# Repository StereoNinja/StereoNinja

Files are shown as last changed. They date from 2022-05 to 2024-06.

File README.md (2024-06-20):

# Stereo Ninja

Stereo Ninja is a DIY digital stereo microscope

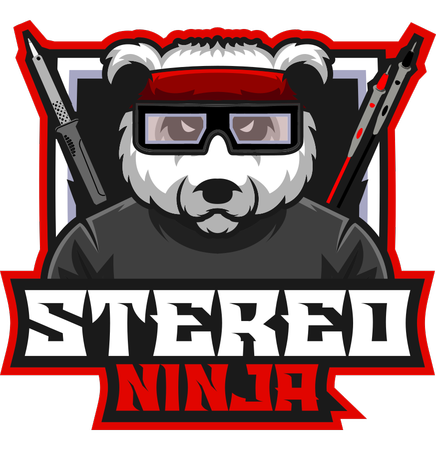
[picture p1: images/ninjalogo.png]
Stereo Ninja Logo


# Overview

If you ever soldered SMT components or looked for issues on one of those tiny PCBs, you know that using a good microscope helps a lot, especially if it is a stereo microscope. But a good stereo microscope comes with a hefty price tag, so it's not for everyone. A cheap alternative is using a "usb microscope", but then of course you do not have stereo vision.

Our idea is to combine best of both worlds. Having proper stereoscopic view on your work piece and using relatively cheap digital components for archiving that. If you already have a 3D capable monitor, you only need a pair of cameras with suitable optics and some electronics for combining the two video streams into a single one that your monitor understands. We are using a Raspberry Pi for that (what else? ;-)).

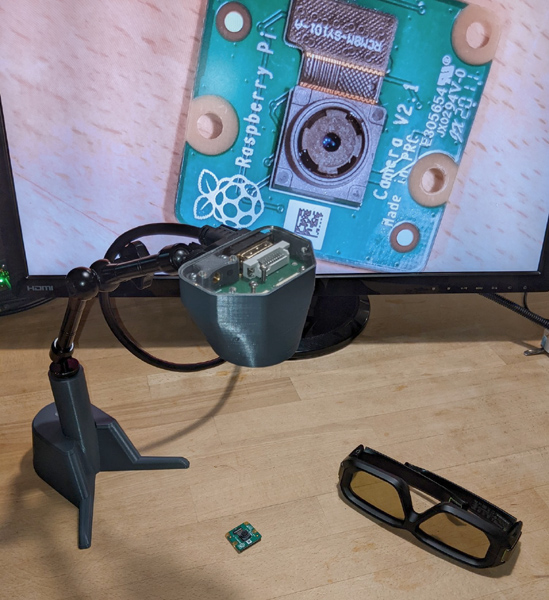
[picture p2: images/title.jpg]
Stereo Ninja


# Details

Stereo Ninja is a dual camera setup for stereoscopic microscopy. The heart of the project is a Raspberry Pi. To be precise, you need a Raspberry Pi 3 or 4 Compute Module and a breakout board that gives you access to both MIPI CSI camera input ports the chip set offers, but is not available at the standard Raspberry Pi 3 or 4 versions. Then of course, you need 2 RaspberryPi-compatible cameras with suitable lenses. Our microscope setup is meant for electronics work, so we chose lenses that do not give you that much of a magnification, but permits an adequate lens-object distance for conveniently working under it. Then of course, you need a 3D monitor for displaying the stereoscopic view on your workpiece. We chose a fast 3D-capable gaming monitor with shutter goggles. Finally, a nice stand for you camera is needed.

All these components allow a selection from a variety of choices. We'll try to come up with a good recommendation on what you would want to get, but it is also possible to mix and match these parts (makes sense e.g. when you already own e.g. a 3d monitor). We'll try to list many of these combinations and document how to get them working. If you try a new lens/camera/board/monitor, let us know how it worked for you!

Here's Uli giving you a quick demo of the Stereo Ninja:

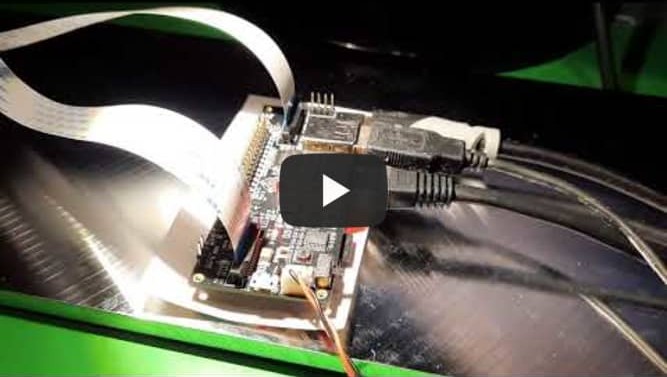
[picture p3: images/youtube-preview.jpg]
Stereo Ninja Intro (https://www.youtube.com/watch?v=p-_V9IuZiU0 "Stereo Ninja Intro")


# Where do I get more information?

This repository is work in progress. More info about what we did so far can be found on [hackaday.io](https://hackaday.io/project/180044-stereo-ninja)

# Roadmap

## Beta release (work in progress)

* Hardware: 
  * Raspberry Pi CM4, Waveshare CM IO Board
  * 2x Raspberry Pi v1 camera + custom lens
  * connection of camera module with Pi with single cable 
* Software
  * Special version of raspivid
  * Outputs side-by-side stereo mode video to be used with 3d monitor
  * User can switch view (digital zoom on/off)
* Documentation
  * BOM
  * Assembly guide

### Todos Beta Release

- [x] Proof-of-Concept: StereoPi + Raspi3 Compute Module: real-time video stream to 3d monitor
- [x] Tests with CM4 (Raspi4 Compute Module)
- [x] Camera module: Dual-camera mount and enclosure (3d printed)
- [x] Camera module: print + test
- [x] Choose cable type for camera module to Pi connection
- [x] Camera board: circuit design 
- [x] Camera board: PCB layout
- [x] Camera board: assembly + testing
- [ ] Finalize Bill of Material
- [ ] Assembly guide / setup instructions

### Todos Release

- [ ] Software: switching between mode 5 (full sensor) and mode 1 (digital zoom)
- [ ] latency optimization: test different software setups, measure latency
- [ ] Select more suitable lenses

## Future feature ideas

* integrate LED lighting
* add buttons e.g. for zooing at camera
* Evaluate possibility the use of standard (non 3D) monitors by generating the signals for the shutter glasses ourselves
* Integrate polarization filter
* software: enable highres photo snapshots
* software: enable streaming/recording
* try to use Raspi v2 compatible cameras (3rd party IMX219 cam with M12 lens mount), see [issue #1](https://github.com/StereoNinja/StereoNinja/issues/1)
* try to use Raspi HQ compatible cameras (3rd party IMX477 cam with M12 lens mount), see [issue #2](https://github.com/StereoNinja/StereoNinja/issues/2)
* smart zoom: zoom into region where your solder tip or test lead points to
* enable video overlay (display PCB info like BOM directly on screen)
* Kicad integration 
* AR mode (e.g. for part placement on PCBs, highlighting tracks, etc)

# FAQ

### I want to build one! Where is the BOM etc?

Hang on for a bit longer. We are preparing the first release. We will have a BOM and all the design files you need by then.

### Do I need a 3D monitor?

Yes. At least for the first version. We are planning a side project that would allow using standard monitors by driving shutter glasses with our own control electronics. But no work has been done on this yet.

### How can I contribute?

At the moment the development is done by a team located at the FabLab München. We are currently not prepared for onboarding 
people who cannot join our in-person meetings. But there are some topics where development could be done quite independently, 
e.g. support for standard monitors (see previous FAQ) or software support for the new Raspberry Pi camera infrastructure.
In any case, if you interested in joining efforts, get in touch!

### How can I get in touch with you?

Drop us an email: stereoninja@fablab-muenchen.de

We are also on twitter: https://twitter.com/_stereoninja

---

Stereo Ninja is a project by FabLab München e.V. It is part of the [MakerTools project](https://wiki.fablab-muenchen.de/pages/viewpage.action?pageId=126815075), which is sponsored by the Federal Ministry of Education and Research.

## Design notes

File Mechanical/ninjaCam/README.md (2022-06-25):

Mechanical CAD/ step files for stereoNinja. Camera Part - ninjaCam

early draft just for demonstration purposes. Probally still some finetuning todo 

Please Note that CAD files may use Models from third parties. Some of used Models: 

License if own work:
CERN-OHL-W 

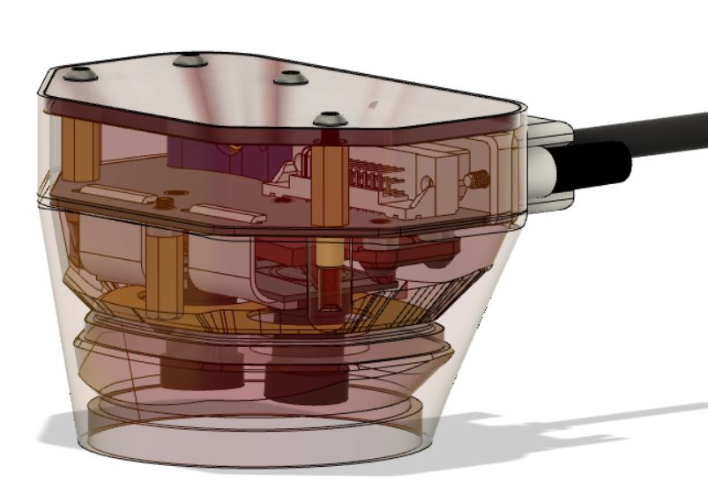
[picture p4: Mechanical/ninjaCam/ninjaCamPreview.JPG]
previw Image


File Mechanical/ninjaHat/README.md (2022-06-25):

Mechanical CAD/ step files for stereoNinja.
early draft just for demonstration purposes. Probally still some finetuning todo 

Please Note that CAD files may use Models from third parties. Some of used Models: 
- Compute Module 4 STEP file aspberry Pi CM4 by Raspberry Pi Foundation
- Waveshare CM4-IO-BASE-B step file  	

License if own work:
CERN-OHL-W 

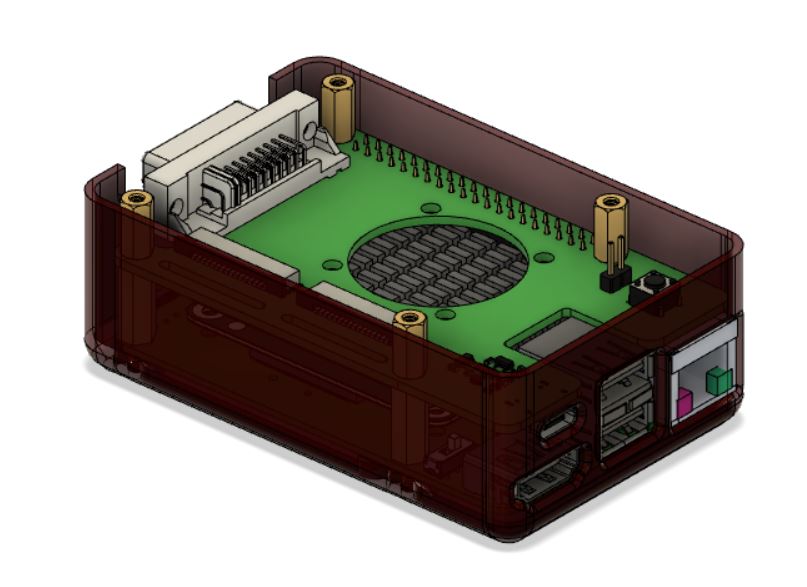
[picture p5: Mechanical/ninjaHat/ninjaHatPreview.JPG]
previw Image


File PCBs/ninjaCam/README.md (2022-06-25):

Empty directory for first Version for "ninjaCam" PCB
Use on your own risk - could create some magic smoke or just not working 

Should be pluged on Waveshare's Mini Base Board for Raspberry CM4. See also Mechanical/Cad files for assembly. 

License of PCB in this directory:
CERN-OHL-W

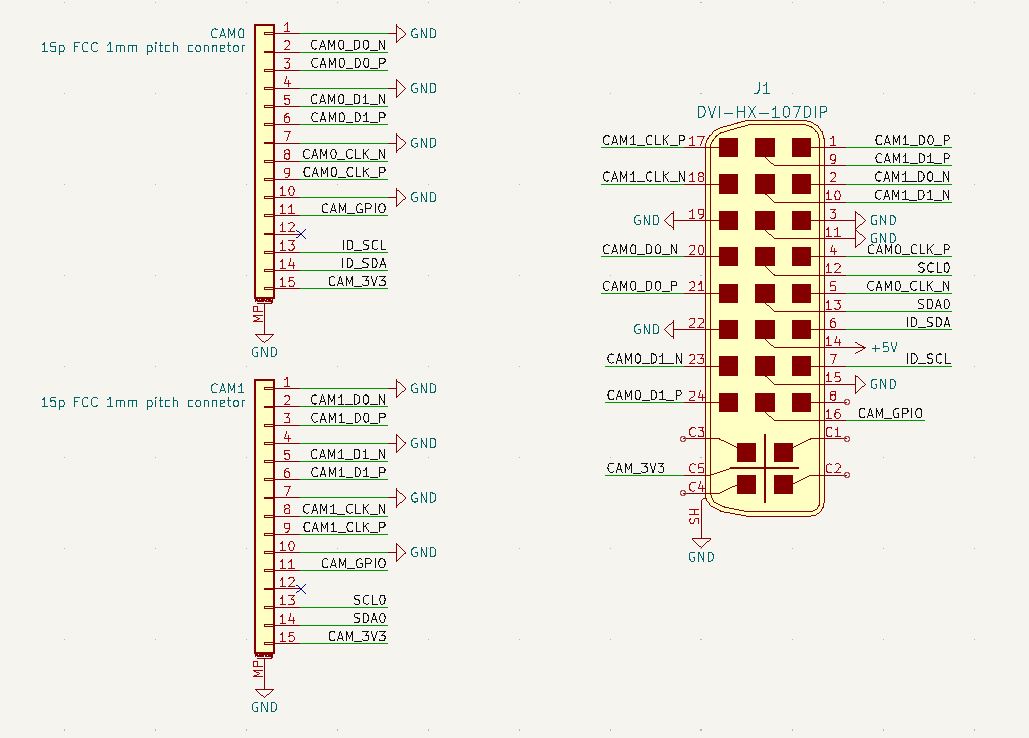
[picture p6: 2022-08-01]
PCBs/ninjaCam/schematic.png

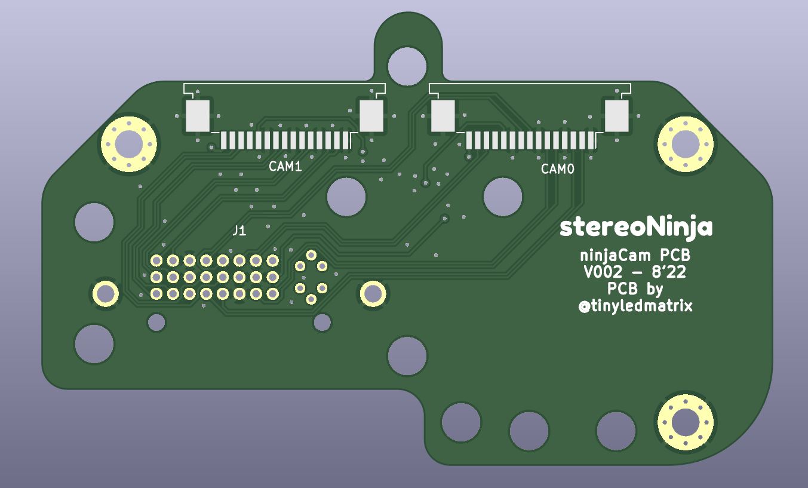
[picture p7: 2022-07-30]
PCBs/ninjaCam/render.jpg

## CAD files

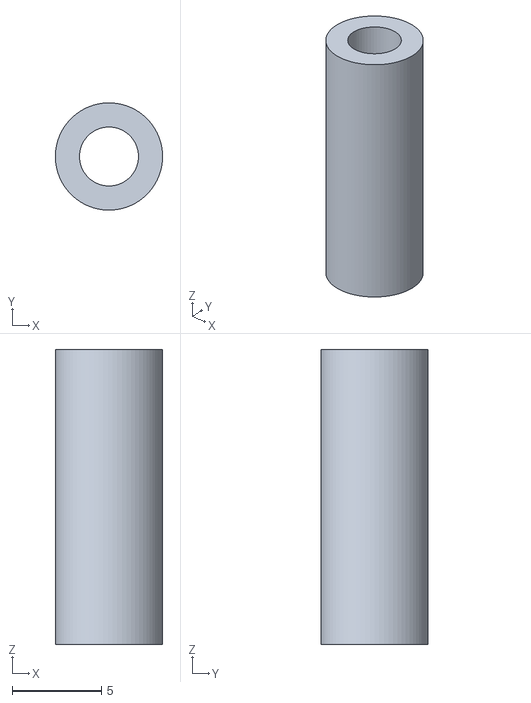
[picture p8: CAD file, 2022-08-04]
Mechanical/ninjaCam/Spacer_2x.stl
6.00 x 6.00 x 16.5

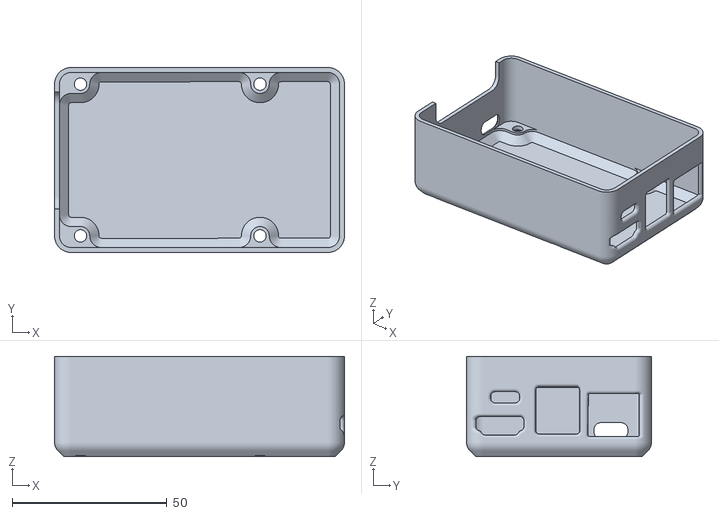
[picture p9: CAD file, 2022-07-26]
Mechanical/ninjaHat/ninjaHat.stl
93.7 x 59.8 x 32.4

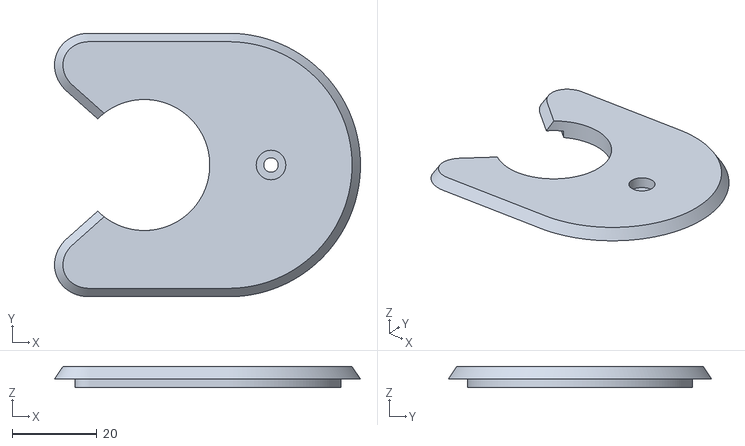
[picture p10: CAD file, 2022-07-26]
Mechanical/ninjaStand/lid.stl
72.4 x 62.4 x 5.00

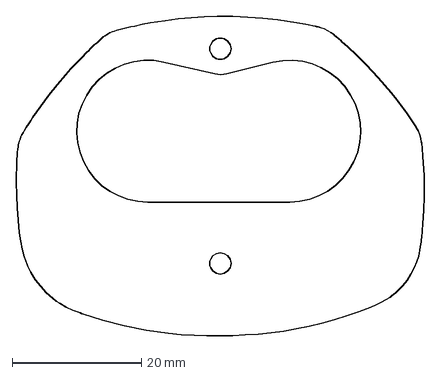
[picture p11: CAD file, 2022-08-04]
Mechanical/ninjaCam/acrylicBot.dxf
63.3 x 49.5 mm

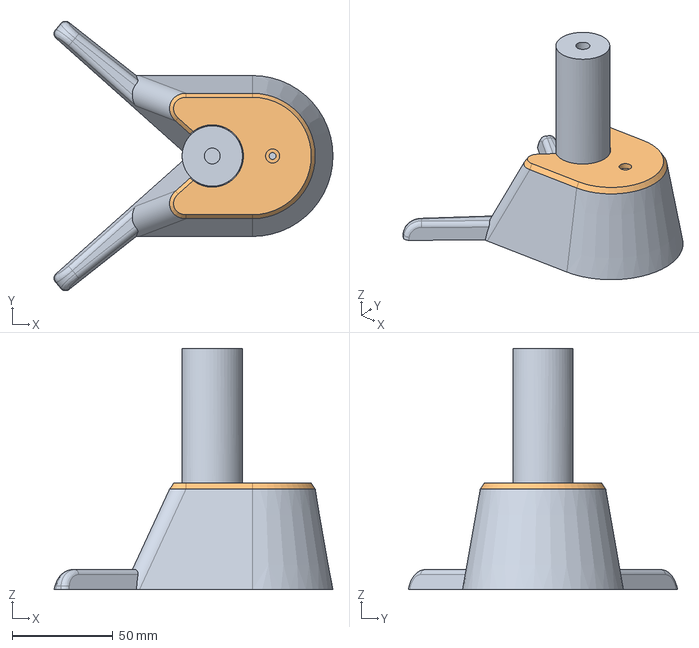
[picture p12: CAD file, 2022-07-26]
Mechanical/ninjaStand/ninjaStand.step
138.7 x 133.9 x 120.0 mm
MagicArmStand
Lid

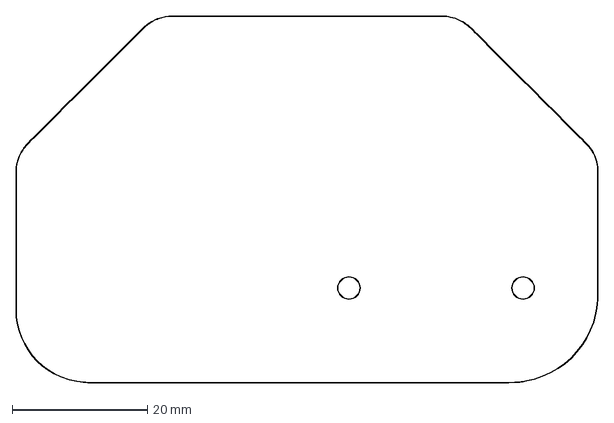
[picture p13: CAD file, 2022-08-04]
Mechanical/ninjaCam/Lid.dxf
86.2 x 54.3 mm

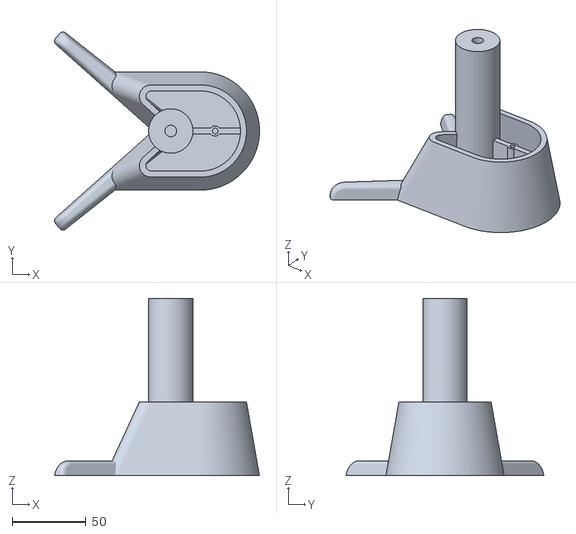
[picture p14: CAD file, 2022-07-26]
Mechanical/ninjaStand/base.stl
138.7 x 133.9 x 120.0

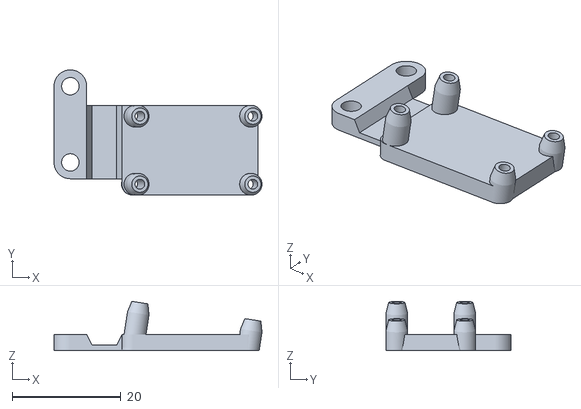
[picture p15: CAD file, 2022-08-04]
Mechanical/ninjaCam/CamHolderB.stl
38.2 x 23.0 x 9.06

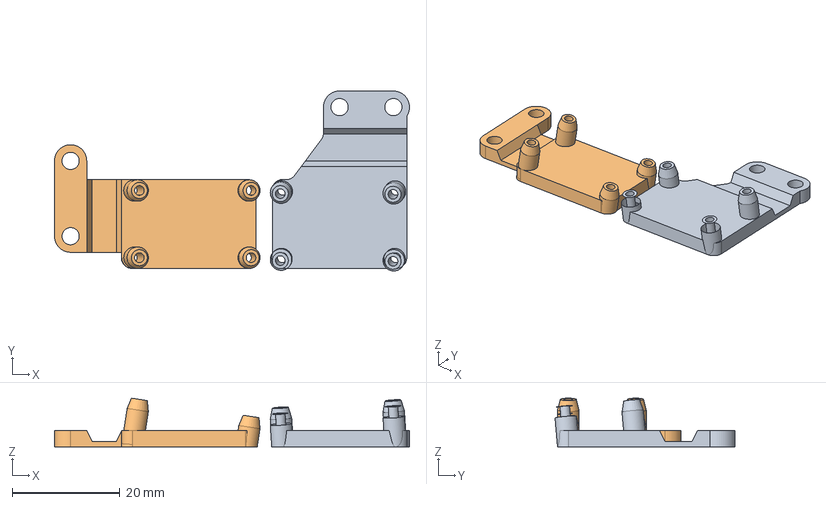
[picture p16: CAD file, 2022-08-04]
Mechanical/ninjaCam/CamHolders.step
66.0 x 33.5 x 9.06 mm

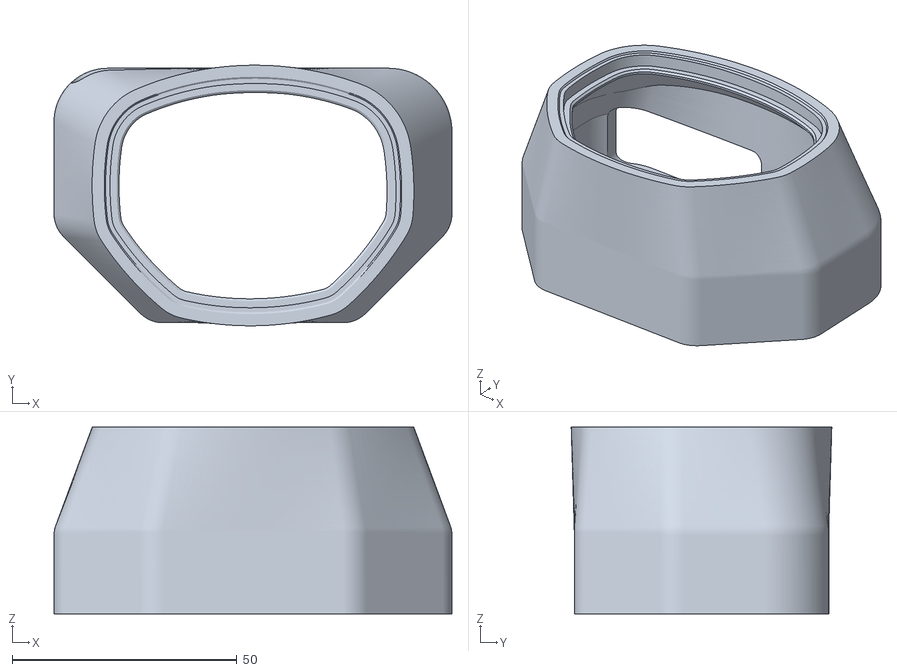
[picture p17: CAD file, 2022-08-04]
Mechanical/ninjaCam/Enclosure.stl
88.6 x 58.0 x 41.5

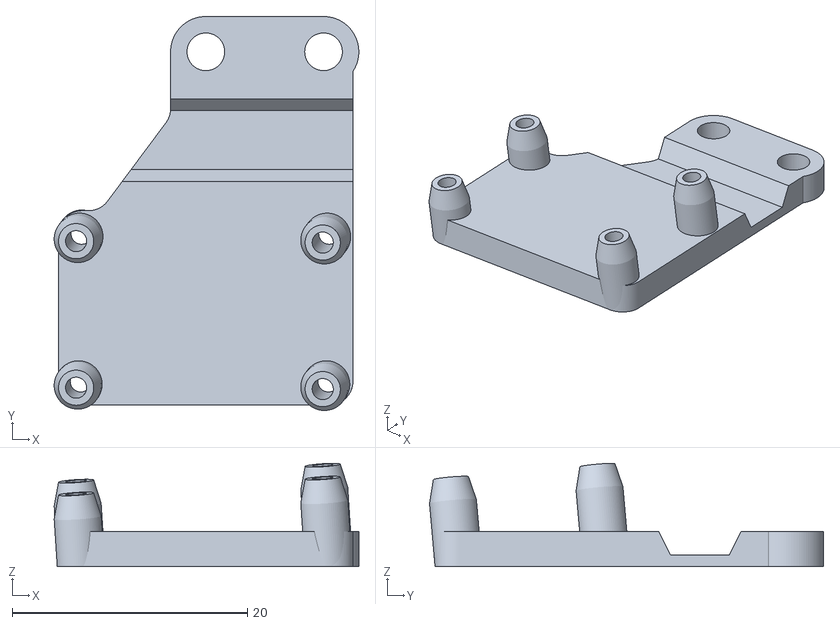
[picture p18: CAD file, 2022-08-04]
Mechanical/ninjaCam/CamHolderA.stl
25.9 x 33.5 x 8.78

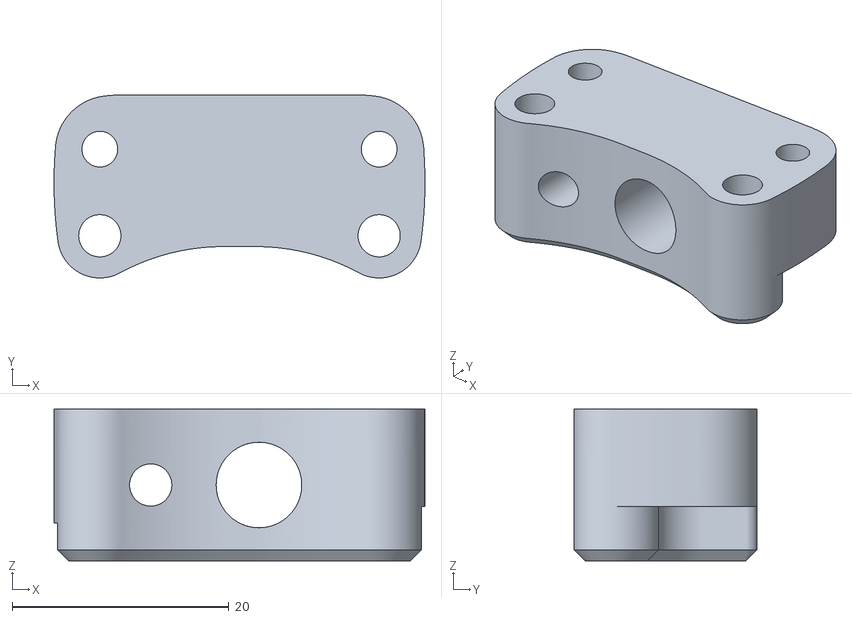
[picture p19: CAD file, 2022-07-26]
Mechanical/ninjaCam/MountingBracket.stl
34.3 x 16.9 x 14.0

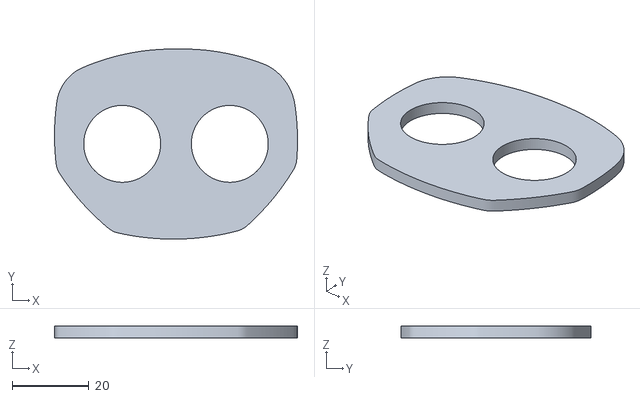
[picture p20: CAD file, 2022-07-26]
Mechanical/ninjaCam/Diffusor.stl
63.2 x 49.5 x 3.00

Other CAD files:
Mechanical/ninjaCam/CamHolders.f3d
Mechanical/ninjaCam/Diffusor.dxf
Mechanical/ninjaStand/ninjaStand.f3d

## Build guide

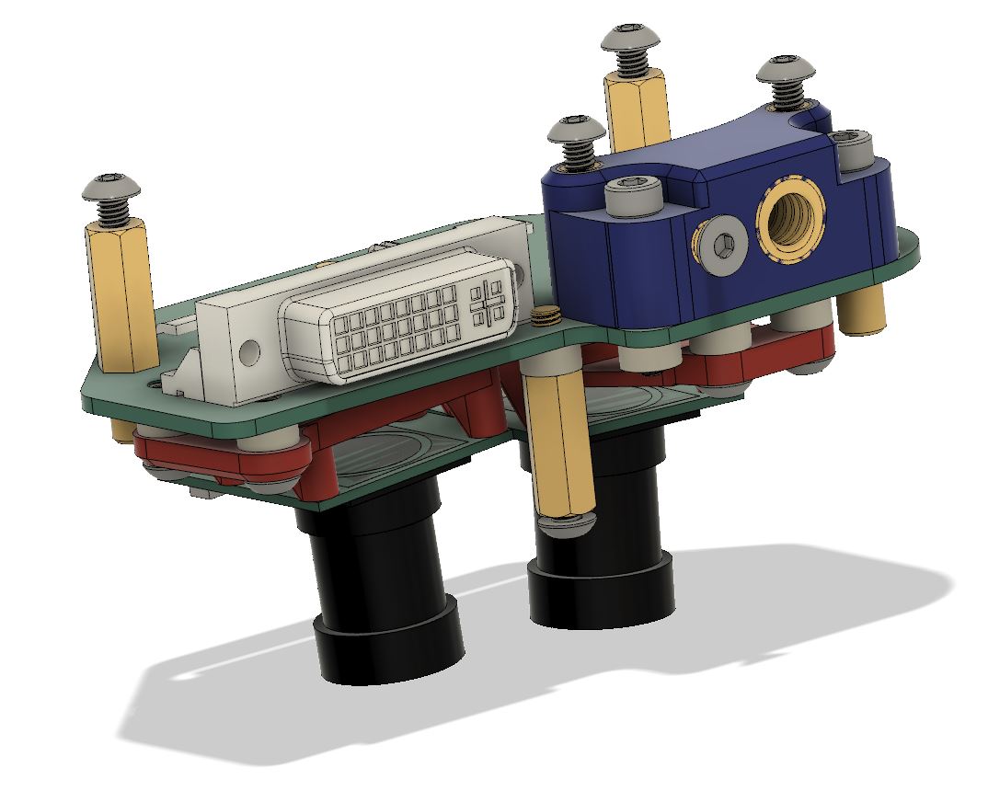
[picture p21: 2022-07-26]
Mechanical/ninjaCam/assembly3.jpg

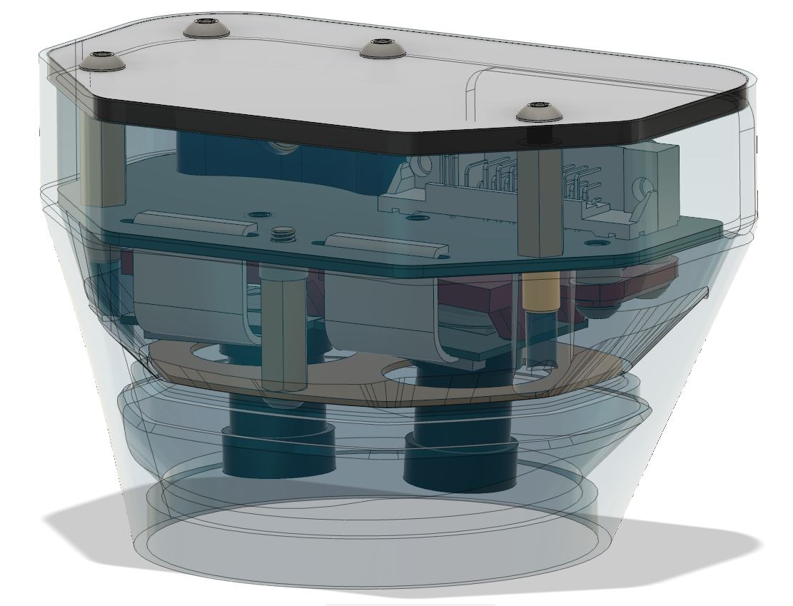
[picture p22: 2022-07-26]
Mechanical/ninjaCam/assembly4.jpg

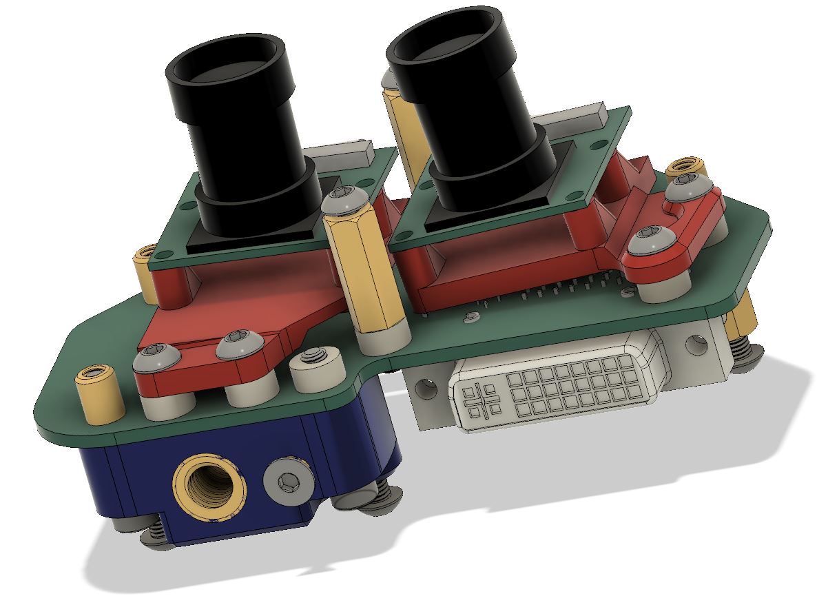
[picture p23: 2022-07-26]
Mechanical/ninjaCam/assembly1.jpg

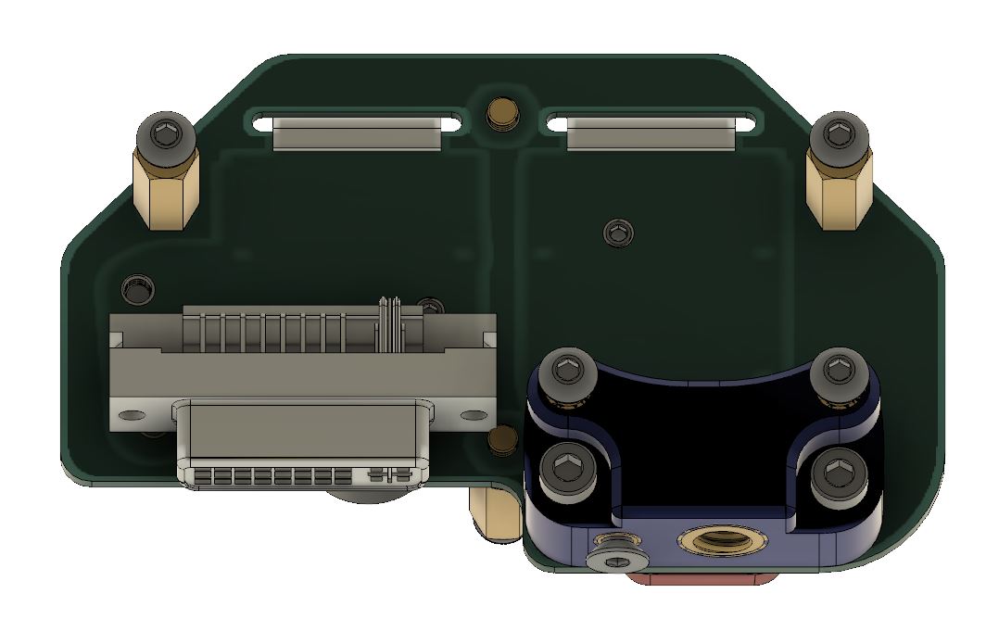
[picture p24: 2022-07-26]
Mechanical/ninjaCam/assembly2.jpg

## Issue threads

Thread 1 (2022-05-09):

Test v2 camera

drayde, 2022-05-09:
The Raspberry Pi v2 camera does not have exchangeable lenses, so it is not suited for Stereo Ninja.
However, there are 3rd party cameras with exchangeable lenses. They have the same sensor (IMX219), but are not Raspberry Pi compatible. This is because the original v2 camera boards have some encryption integrated, and without that they do not work with the Pi boards. However, for compute modules, the encryption is not done and the 3rd camera do work.
One camera we could test this with is the https://www.waveshare.com/IMX219-160-Camera.htm

drayde, 2022-07-13:
Another possibility is to use an original v2 cam board and replace the cam with a Waveshare 15264 https://www.waveshare.com/imx219-d160.htm

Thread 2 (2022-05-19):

Test HQ camera

drayde, 2022-05-19:
Similar to #1 but with HQ compatible IMX477 cam.
Possible cameras to use:
* [Arducam B0271](https://www.arducam.com/product/arducam-mini-high-quality-camera-with-m12-mount-lens-for-raspberry-pi-cm-cm3-cm3-cm4-b0271/)
* [Arducam B0251](https://www.arducam.com/product/arducam-12mp-imx477-mini-high-quality-camera-module-for-raspberry-pi/)

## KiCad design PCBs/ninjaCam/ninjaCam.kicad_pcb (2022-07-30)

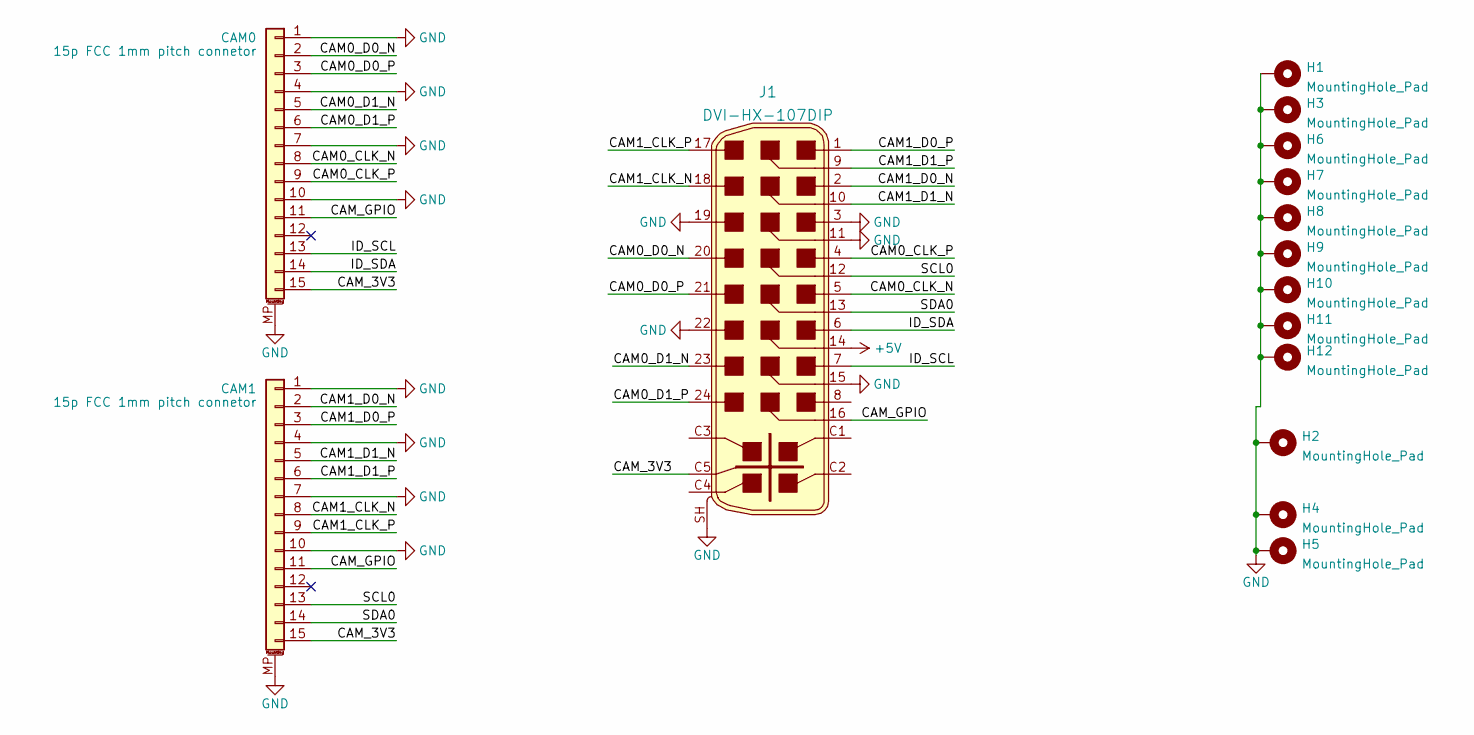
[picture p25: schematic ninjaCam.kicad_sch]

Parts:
CAM0, CAM1: 15p FCC 1mm pitch connetor; TE_1-84952-5_1x15-1MP_P1.0mm_Horizontal
H1, H3, H6, H7, H8, H9, H10, H11, H12: MountingHole_Pad; WA-SMSI_9774010360
H2, H4, H5: MountingHole_Pad; MountingHole_3.2mm_M3_Pad_Via
J1: DVI-HX-107DIP; DVI_Female_74320-9010; MPN DVI-HX-107DIP; LCSC# C2936242

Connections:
+5V: J1.14
/CAM0_CLK_N: CAM0.8, J1.5
/CAM0_CLK_P: CAM0.9, J1.4
/CAM0_D0_N: CAM0.2, J1.20
/CAM0_D0_P: CAM0.3, J1.21
/CAM0_D1_N: CAM0.5, J1.23
/CAM0_D1_P: CAM0.6, J1.24
/CAM1_CLK_N: CAM1.8, J1.18
/CAM1_CLK_P: CAM1.9, J1.17
/CAM1_D0_N: CAM1.2, J1.2
/CAM1_D0_P: CAM1.3, J1.1
/CAM1_D1_N: CAM1.5, J1.10
/CAM1_D1_P: CAM1.6, J1.9
/CAM_3V3: CAM0.15, CAM1.15, J1.C5
/CAM_GPIO: CAM0.11, CAM1.11, J1.16
/ID_SCL: CAM0.13, J1.7
/ID_SDA: CAM0.14, J1.6
/SCL0: CAM1.13, J1.12
/SDA0: CAM1.14, J1.13
GND: CAM0.1, CAM0.4, CAM0.7, CAM0.10, CAM0.MP (MountPin), CAM1.1, CAM1.4, CAM1.7, CAM1.10, CAM1.MP (MountPin), H1.1, H2.1, H3.1, H4.1, H5.1, H6.1, H7.1, H8.1, H9.1, H10.1, H11.1, H12.1, J1.3, J1.11, J1.15, J1.19, J1.22, J1.SH

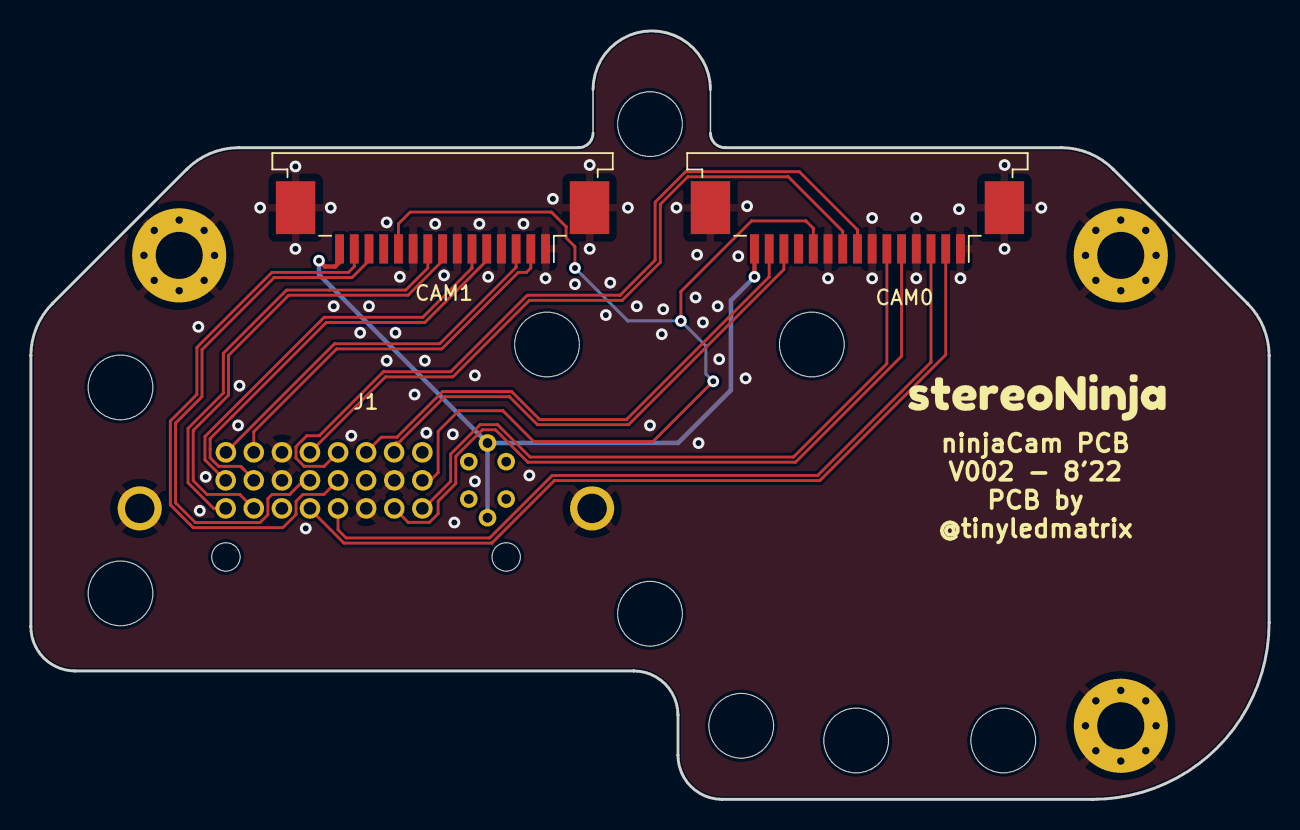
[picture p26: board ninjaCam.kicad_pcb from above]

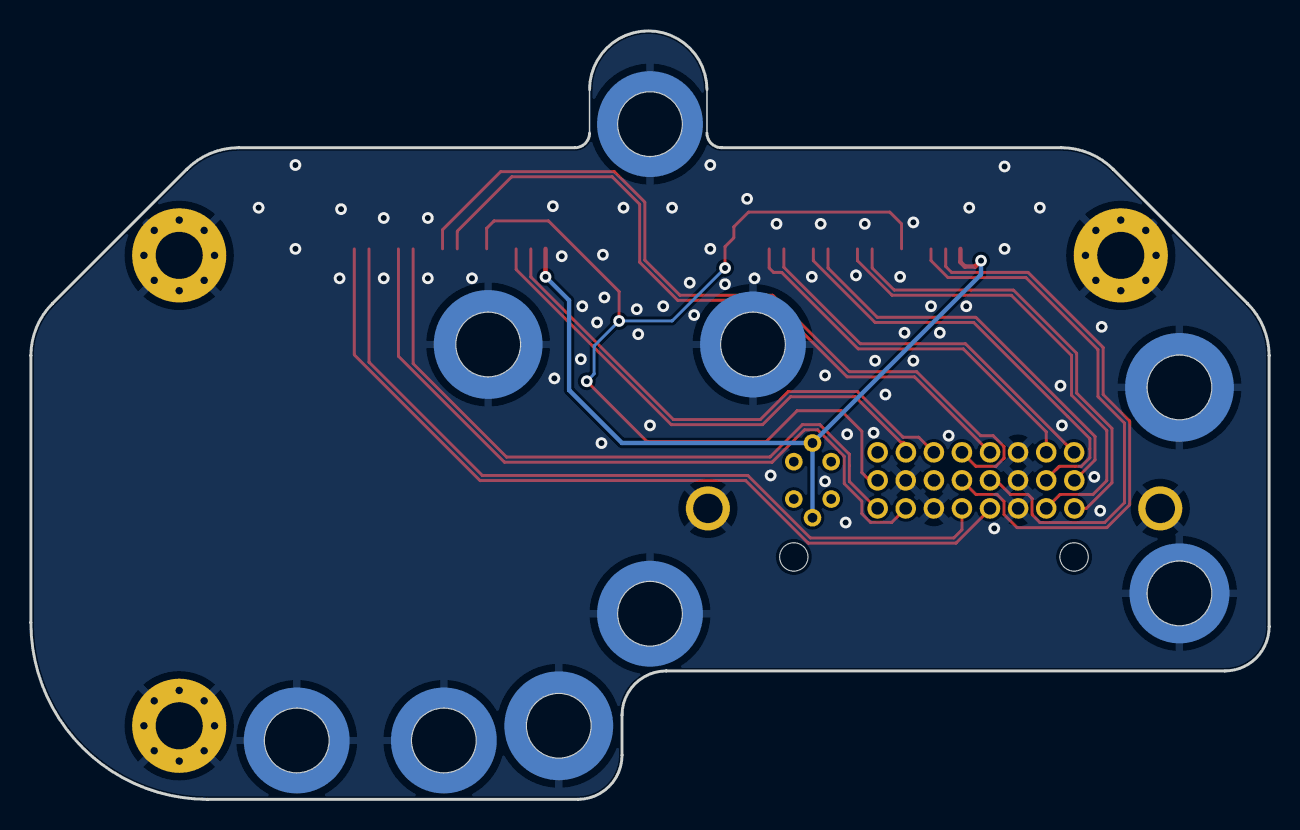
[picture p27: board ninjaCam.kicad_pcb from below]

Board: 2 copper layers, 84.2 x 52.2 mm, 16 parts (9 on the bottom side), 19 nets.

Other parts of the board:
kibuzzard-62BCCBE5: G***; kibuzzard-62BCCBE5

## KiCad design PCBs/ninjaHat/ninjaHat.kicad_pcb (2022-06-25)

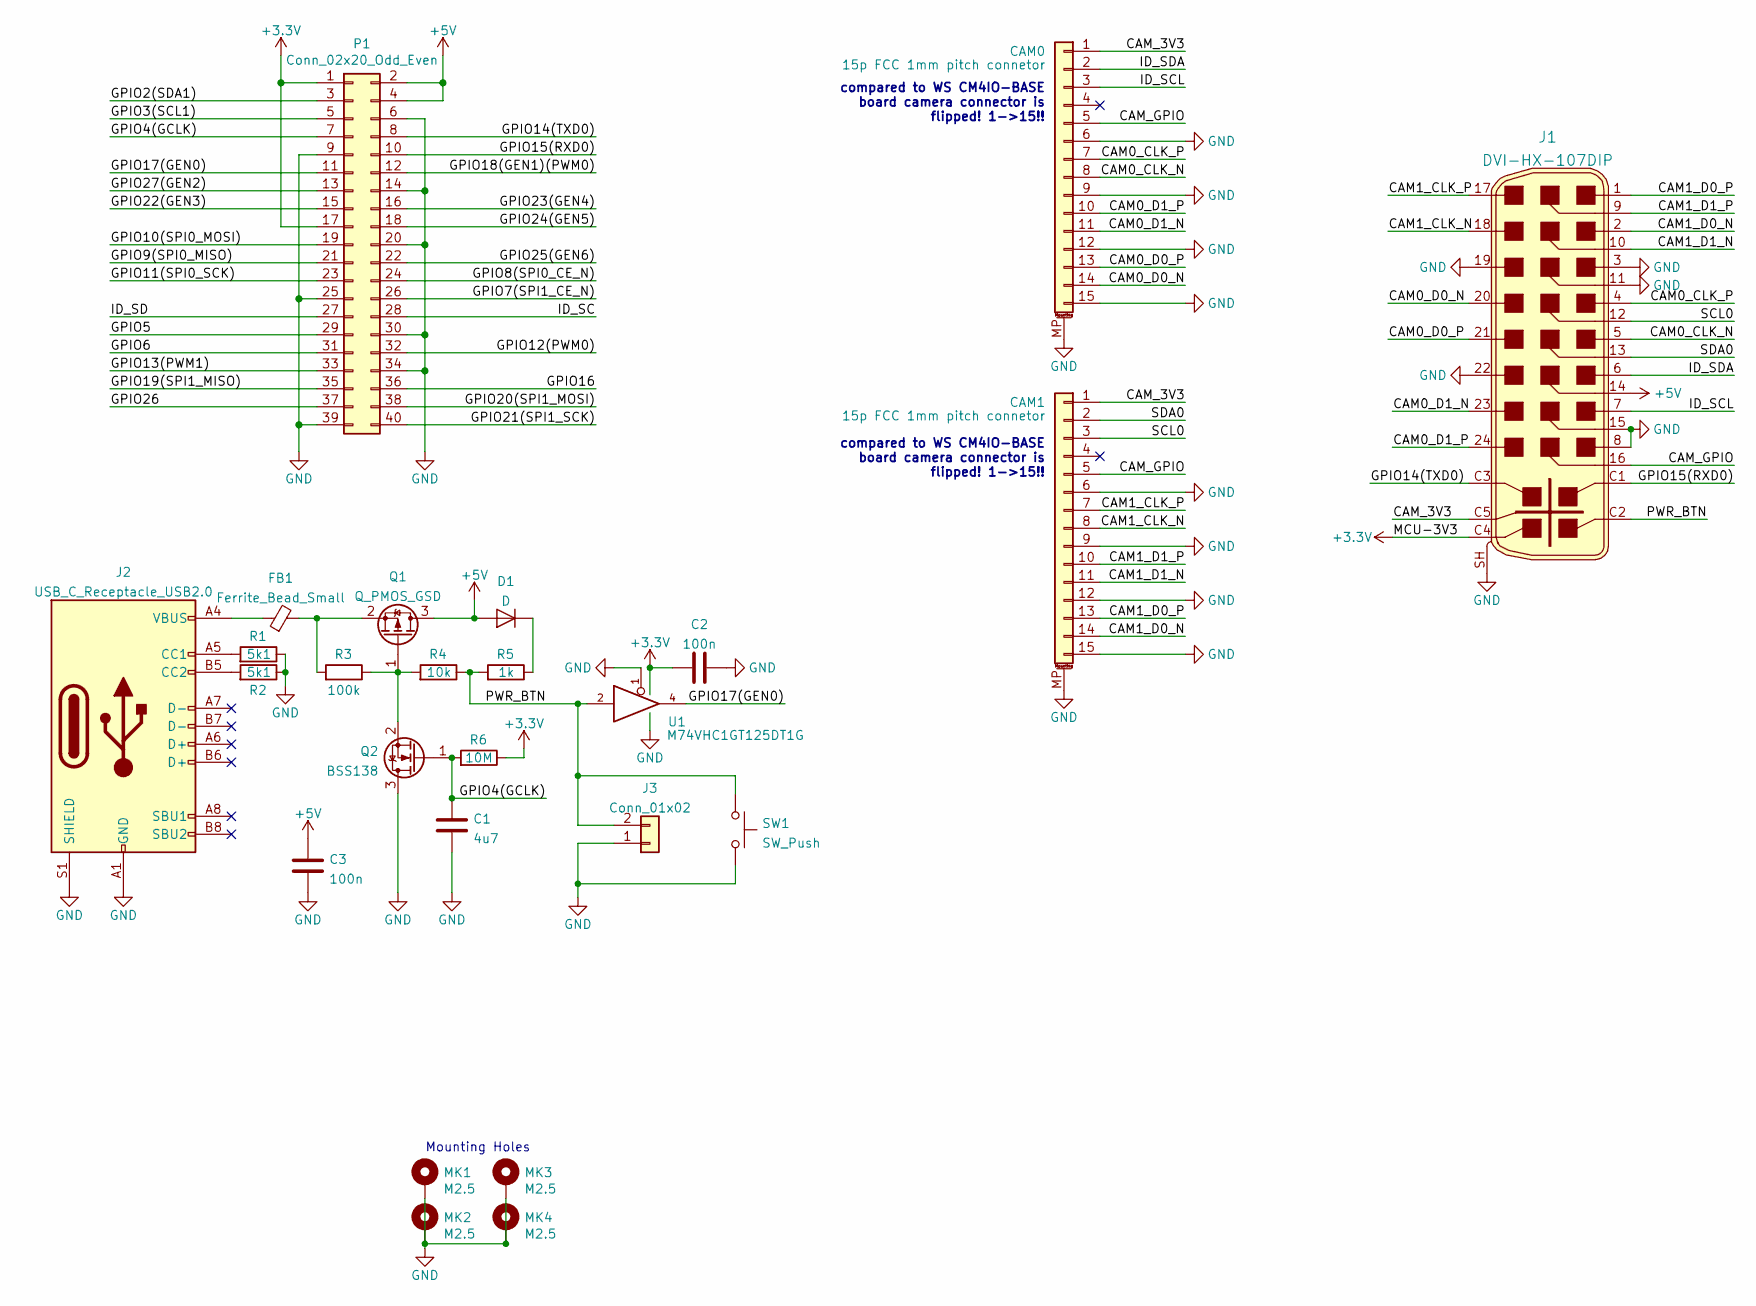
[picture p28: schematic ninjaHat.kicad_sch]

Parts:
C1: 4u7; C_0603_min
C2, C3: 100n; C_0603_min
CAM0, CAM1: 15p FCC 1mm pitch connetor; TE_1-84952-5_1x15-1MP_P1.0mm_Horizontal
D1: D; D_SOD-323
FB1: Ferrite_Bead_Small; L_0603_min
J1: DVI-HX-107DIP; DVI_Female_74320-9010; MPN DVI-HX-107DIP; LCSC# C2936242
J2: USB_C_Receptacle_USB2.0; USB_C_Receptacle_GT-USB-7010
J3: Conn_01x02; PinHeader_1x02_P2.54mm_Vertical
MK1, MK2, MK3, MK4: M2.5; MountingHole_3.2mm_M3_Pad_Via
P1: Conn_02x20_Odd_Even; PinSocket_2x20_P2.54mm_Vertical
Q1: Q_PMOS_GSD; SOT-23
Q2: BSS138; SOT-23
R1, R2: 5k1; R_0603_min
R3: 100k; R_0603_min
R4: 10k; R_0603_min
R5: 1k; R_0603_min
R6: 10M; R_0603_min
SW1: SW_Push; SW_PUSH_6mm
U1: M74VHC1GT125DT1G; TSOP-5_1.65x3.05mm_P0.95mm

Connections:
+3V3: C2.1, J1.C4, P1.1, P1.17, R6.1, U1.5 (VCC)
+5V: C3.2, D1.2 (A), J1.14, P1.2, P1.4, Q1.3 (D)
/CAM0_CLK_N: CAM0.8, J1.5
/CAM0_CLK_P: CAM0.7, J1.4
/CAM0_D0_N: CAM0.14, J1.20
/CAM0_D0_P: CAM0.13, J1.21
/CAM0_D1_N: CAM0.11, J1.23
/CAM0_D1_P: CAM0.10, J1.24
/CAM1_CLK_N: CAM1.8, J1.18
/CAM1_CLK_P: CAM1.7, J1.17
/CAM1_D0_N: CAM1.14, J1.2
/CAM1_D0_P: CAM1.13, J1.1
/CAM1_D1_N: CAM1.11, J1.10
/CAM1_D1_P: CAM1.10, J1.9
/CAM_3V3: CAM0.1, CAM1.1, J1.C5
/CAM_GPIO: CAM0.5, CAM1.5, J1.16
/GPIO2(SDA1): P1.3
/GPIO3(SCL1): P1.5
/GPIO4(GCLK): C1.1, P1.7, Q2.1 (G), R6.2
/GPIO5: P1.29
/GPIO6: P1.31
/GPIO7(SPI1_CE_N): P1.26
/GPIO8(SPI0_CE_N): P1.24
/GPIO9(SPI0_MISO): P1.21
/GPIO10(SPI0_MOSI): P1.19
/GPIO11(SPI0_SCK): P1.23
/GPIO12(PWM0): P1.32
/GPIO13(PWM1): P1.33
/GPIO14(TXD0): J1.C3, P1.8
/GPIO15(RXD0): J1.C1, P1.10
/GPIO16: P1.36
/GPIO17(GEN0): P1.11, U1.4
/GPIO18(GEN1)(PWM0): P1.12
/GPIO19(SPI1_MISO): P1.35
/GPIO20(SPI1_MOSI): P1.38
/GPIO21(SPI1_SCK): P1.40
/GPIO22(GEN3): P1.15
/GPIO23(GEN4): P1.16
/GPIO24(GEN5): P1.18
/GPIO25(GEN6): P1.22
/GPIO26: P1.37
/GPIO27(GEN2): P1.13
/ID_SC: P1.28
/ID_SCL: CAM0.3, J1.7
/ID_SD: P1.27
/ID_SDA: CAM0.2, J1.6
/PWR_BTN: J1.C2, J3.2, R4.1, R5.2, SW1.1, U1.2
/SCL0: CAM1.3, J1.12
/SDA0: CAM1.2, J1.13
GND: C1.2, C2.2, C3.1, CAM0.6, CAM0.9, CAM0.12, CAM0.15, CAM0.MP (MountPin), CAM1.6, CAM1.9, CAM1.12, CAM1.15, CAM1.MP (MountPin), J1.3, J1.8, J1.11, J1.15, J1.19, J1.22, J1.SH, J2.A1 (GND), J2.A12 (GND), J2.B1 (GND), J2.B12 (GND), J2.S1 (SHIELD), J3.1, MK1.1, MK2.1, MK3.1, MK4.1, P1.6, P1.9, P1.14, P1.20, P1.25, P1.30, P1.34, P1.39, Q2.3 (D), R1.1, R2.1, SW1.2, U1.1, U1.3 (GND)
unnamed: D1.1 (K), R5.1
unnamed: FB1.1, J2.A4 (VBUS), J2.A9 (VBUS), J2.B4 (VBUS), J2.B9 (VBUS)
unnamed: FB1.2, Q1.2 (S), R3.2
unnamed: J2.A5 (CC1), R1.2
unnamed: J2.B5 (CC2), R2.2
unnamed: Q1.1 (G), Q2.2 (S), R3.1, R4.2

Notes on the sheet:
compared to WS CM4IO-BASE board camera connector is flipped! 1->15!!
Mounting Holes

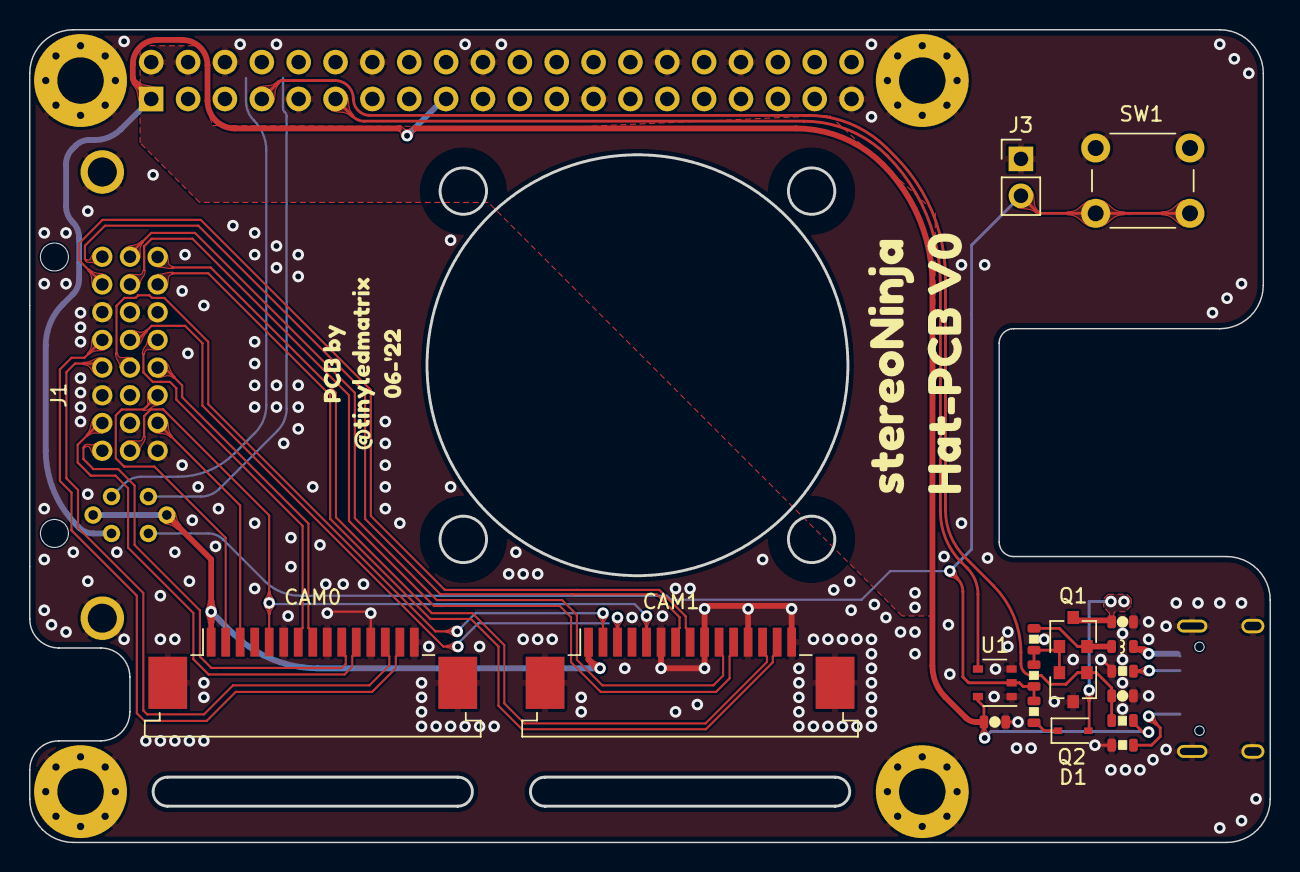
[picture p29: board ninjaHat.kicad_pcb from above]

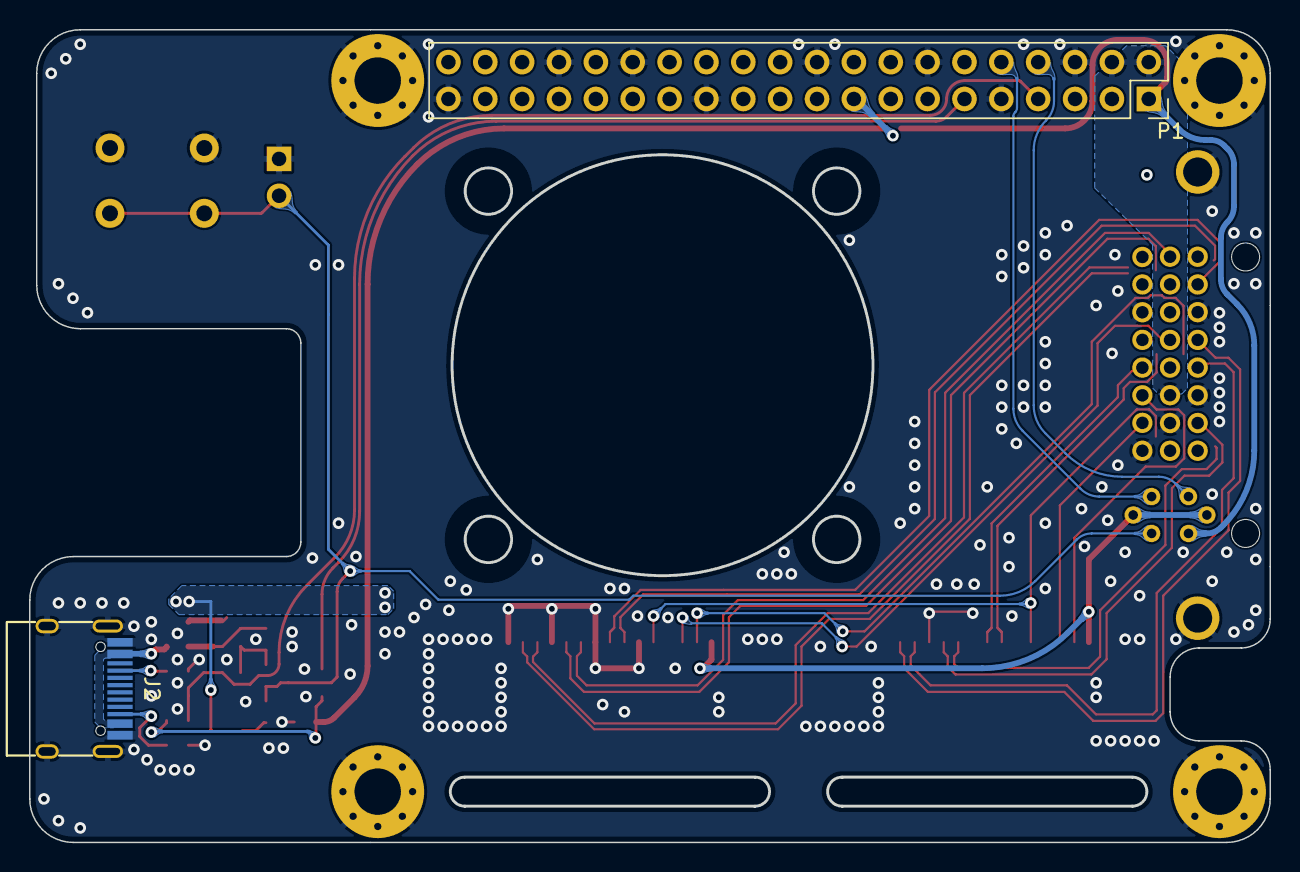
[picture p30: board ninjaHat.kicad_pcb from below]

Board: 2 copper layers, 85.5 x 56.0 mm, 29 parts (2 on the bottom side), 32 nets.

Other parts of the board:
kibuzzard-62A7984C: G***; kibuzzard-62A7984C
kibuzzard-62A79922: G***; kibuzzard-62A79922
kibuzzard-62A79934: G***; kibuzzard-62A79934
kibuzzard-62A79947: G***; kibuzzard-62A79947

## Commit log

2022-05-13 added files for 3d printing
    [DualCamFixture.f3z, DualCamFixture.step, DualCamFixture.stl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]
2022-06-25 Added PCB kicad files for HAT-PCB
    see also readme
    [ninjaHat.kicad_pcb, ninjaHat.kicad_sch]
2022-06-25 prepared empty directory for upcoming ninjaCAM PCB
2022-06-25 added machanical data for eraly draft of camera part
    just for demonstration probably not working good
2022-07-06 removed old files
    [DualCamFixture.f3z, DualCamFixture.step, DualCamFixture.stl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]
2022-07-06 added NinjaStand files, Fusion version v10
    [base.stl, lid.stl, ninjaStand.f3d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]
2022-07-06 added ninjaCam STL files
    [CamMount1.stl, CamMount2.stl, Diffusor.dxf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]
2022-07-06 more screenshots of the assembly
2022-07-06 moved DVI cutout a bit to the left
    [ninjaHat.stl]
2022-07-29 Added ninjaCam V002 - untested!
    [ninjaCam.kicad_pcb, ninjaCam.kicad_sch]
2022-07-30 moved one pair of mounting holes (for cam holder) to be x=50mm y=10mm relative to other cam holder mounting hole
    [ninjaCam.kicad_pcb]
2022-07-30 updated pcb render
2022-08-01 added schematic as png
2022-08-04 New camholders
    [CamHolderA.stl, CamHolderB.stl, CamHolders.f3d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]
2022-08-04 Additional Files for printing Laser cutting
    [Spacer_2x.stl, acrylicBot.dxf]
2022-08-04 connected pin8 of VGa to GND was NC before
    on hat/fpga also connected to gnd
    [ninjaCam.kicad_sch]
